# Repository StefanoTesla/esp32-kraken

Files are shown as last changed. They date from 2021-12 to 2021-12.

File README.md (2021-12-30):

# esp32 Kraken
A funny name for a simple pcb for a esp32 prototipe, designed to use all i/o as input and output with different configurations

This board is deisgned to imporve the quality of development forgetting the protobard with folating wires and no-contact noise.

The pcb is designed by eagle

The size of the board is 100x100mm perfect to pass as prototype in jlcpb and get it at a low price (around 22$ for 5 boards).

Currently the pcb is designed to fit with esp32 dev kit with 30pins

The pcb.zip file contain the geber file to upload in your favourite pcb manufacturing site ♥️

<p align="center">
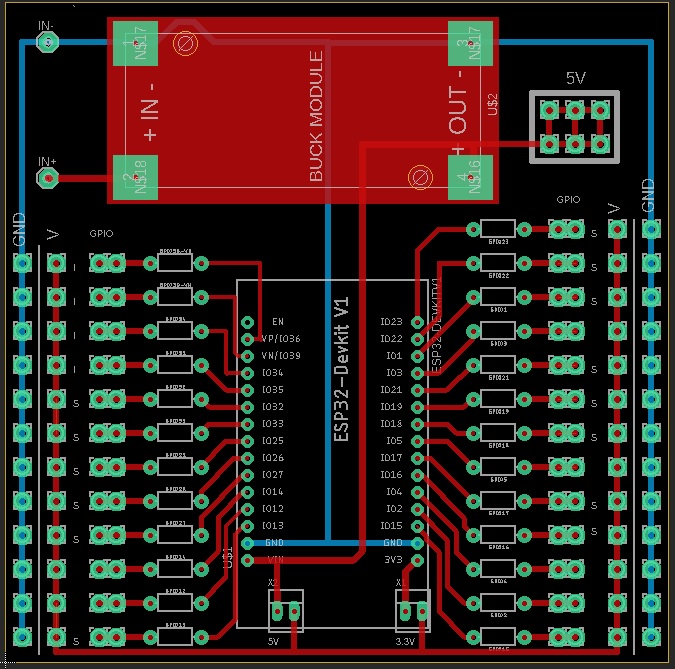
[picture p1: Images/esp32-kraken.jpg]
  
</p>

## How does it work?

Very well! 🙂 with this configuration you don't have limit, all I/O are ready to use in all the way you can think let's take a look:

### Power supply

If you want you can add a LM2596 DC-DC step down, otherwise you can give 5V directly on OUT+ and OUT-

<p align="center">
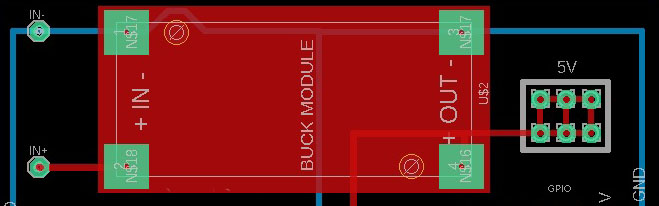
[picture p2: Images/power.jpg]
  
</p>

In the right side there's some 5V spare pins where you can pluc i2c devices or what you want

### V voltage selector
As you can see there's a GND and a V pin for each input, you can choose the V voltage as you prefer in 5V or 3.3V bridgin one of the the selector in the buttom, or give your own voltage to the V line (this will help cause 3.3V are providev from internal esp32 voltage regulator

<p align="center">
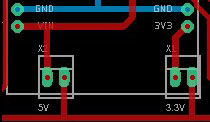
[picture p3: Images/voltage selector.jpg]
  
</p>

### Input

Free to choose in wich way you wanna use it, in the past I hade some problem using internal pull up/pull down resistor and this is why I build this board in a first step.

You can provide olso 5V signal to the esp32 adding a zener diode, or a fancy 10K resistor but after don't cry if your esp32 blow up 🤯 furthermore the ground of all two system shuold be connected between

#### External Pull Up/Down Resistor

Pull down:
<p align="center">
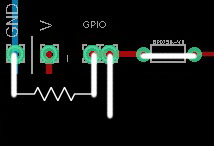
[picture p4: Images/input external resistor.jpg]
  
</p>

Pull Up
<p align="center">
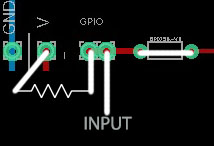
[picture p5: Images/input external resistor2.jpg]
  
</p>

#### Directly input

You can give olso direct input of coure in two way, the white one, is more boring, you need a bridge but can be useful if you neet to measure the volatage, for the listless there's olso the red one solution

<p align="center">
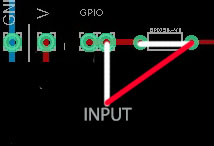
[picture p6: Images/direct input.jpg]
  
</p>

#### Others funny thing you can do

You can use a zener with resistor for limit the voltage, you can use a capacitor with a resistor for having an external debounce system, but be careful adding a lot of thing or your board become a christmas tree 🎄

### Output

Output can be use in three differt way, directly like the input with the same method, you can usa a bridge to measuere the voltage (yellow way) or plug the wire directly before gpio resistance (white way) , if you wanna plug a led you can simply add a resistor in the appropriate space (red way)

<p align="center">
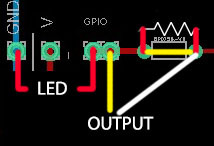
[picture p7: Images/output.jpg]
  
</p>

### Board notes

If you are not myopic you can see an I or an S near some GPIO, what they mean???

I stand for Only-Input GPIO

S stand for "Safety" that is you can use that output without going to have problems like pwm at the boot

<p align="center">
  
</p>

## Hope you like it!

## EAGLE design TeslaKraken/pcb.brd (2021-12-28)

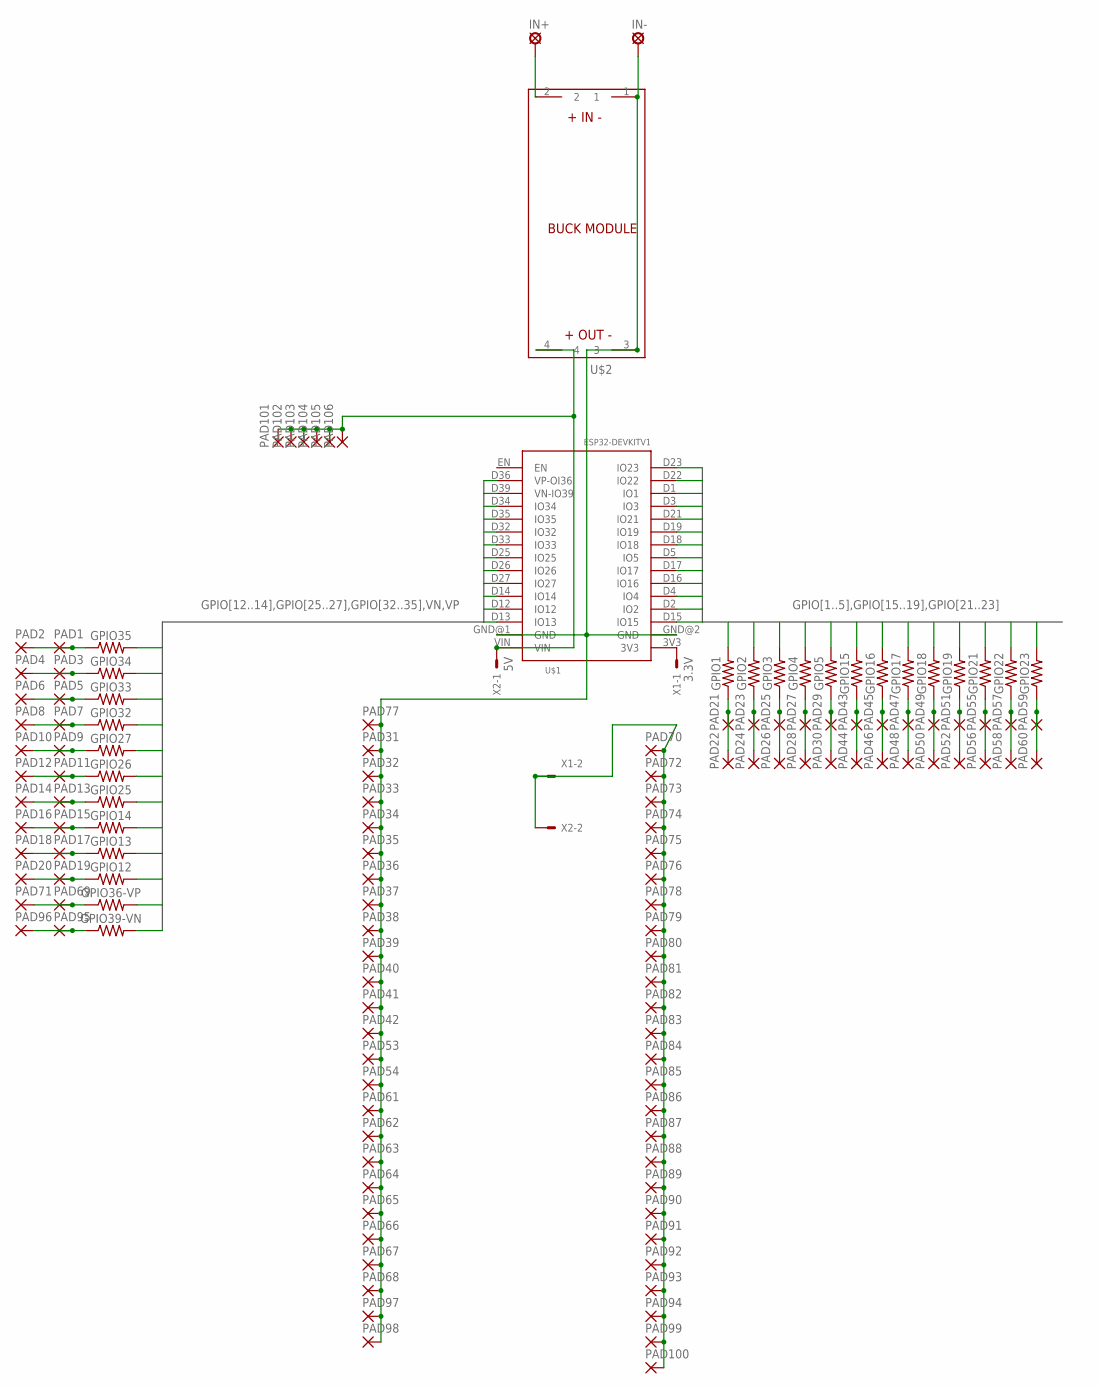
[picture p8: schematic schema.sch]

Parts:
GPIO1, GPIO2, GPIO3, GPIO4, GPIO5, GPIO12, GPIO13, GPIO14, GPIO15, GPIO16, GPIO17, GPIO18, GPIO19, GPIO21, GPIO22, GPIO23, GPIO25, GPIO26, GPIO27, GPIO32, GPIO33, GPIO34, GPIO35, GPIO36-VP, GPIO39-VN: AXIAL-0.3-KIT
IN+: SE14
IN-: SE14
PAD1, PAD2, PAD3, PAD4, PAD5, PAD6, PAD7, PAD8, PAD9, PAD10, PAD11, PAD12, PAD13, PAD14, PAD15, PAD16, PAD17, PAD18, PAD19, PAD20, PAD21, PAD22, PAD23, PAD24, PAD25, PAD26, PAD27, PAD28, PAD29, PAD30, PAD31, PAD32, PAD33, PAD34, PAD35, PAD36, PAD37, PAD38, PAD39, PAD40, PAD41, PAD42, PAD43, PAD44, PAD45, PAD46, PAD47, PAD48, PAD49, PAD50, PAD51, PAD52, PAD53, PAD54, PAD55, PAD56, PAD57, PAD58, PAD59, PAD60, PAD61, PAD62, PAD63, PAD64, PAD65, PAD66, PAD67, PAD68, PAD69, PAD70, PAD71, PAD72, PAD73, PAD74, PAD75, PAD76, PAD77, PAD78, PAD79, PAD80, PAD81, PAD82, PAD83, PAD84, PAD85, PAD86, PAD87, PAD88, PAD89, PAD90, PAD91, PAD92, PAD93, PAD94, PAD95, PAD96, PAD97, PAD98, PAD99, PAD100, PAD101, PAD102, PAD103, PAD104, PAD105, PAD106: 2,54/1,1
U$1: ESP32DEVKITV1; ESP32-DEVKITV1
U$2: BUCK_MODULEWITH_SMDPADS&THROUGHHOLES; BUCK_MODULE
X1: 3.3V; 22-23-2021
X2: 5V; 22-23-2021

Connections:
GPIO1: GPIO1.P$2 (2), U$1.D1 (IO1)
GPIO2: GPIO2.P$2 (2), U$1.D2 (IO2)
GPIO3: GPIO3.P$2 (2), U$1.D3 (IO3)
GPIO4: GPIO4.P$2 (2), U$1.D4 (IO4)
GPIO5: GPIO5.P$2 (2), U$1.D5 (IO5)
GPIO12: GPIO12.P$2 (2), U$1.D12 (IO12)
GPIO13: GPIO13.P$2 (2), U$1.D13 (IO13)
GPIO14: GPIO14.P$2 (2), U$1.D14 (IO14)
GPIO15: GPIO15.P$2 (2), U$1.D15 (IO15)
GPIO16: GPIO16.P$2 (2), U$1.D16 (IO16)
GPIO17: GPIO17.P$2 (2), U$1.D17 (IO17)
GPIO18: GPIO18.P$2 (2), U$1.D18 (IO18)
GPIO19: GPIO19.P$2 (2), U$1.D19 (IO19)
GPIO21: GPIO21.P$2 (2), U$1.D21 (IO21)
GPIO22: GPIO22.P$2 (2), U$1.D22 (IO22)
GPIO23: GPIO23.P$2 (2), U$1.D23 (IO23)
GPIO25: GPIO25.P$2 (2), U$1.D25 (IO25)
GPIO26: GPIO26.P$2 (2), U$1.D26 (IO26)
GPIO27: GPIO27.P$2 (2), U$1.D27 (IO27)
GPIO32: GPIO32.P$2 (2), U$1.D32 (IO32)
GPIO33: GPIO33.P$2 (2), U$1.D33 (IO33)
GPIO34: GPIO34.P$2 (2), U$1.D34 (IO34)
GPIO35: GPIO35.P$2 (2), U$1.D35 (IO35)
unnamed: GPIO35.P$1 (1), PAD1.1, PAD2.1
unnamed: GPIO34.P$1 (1), PAD3.1, PAD4.1
unnamed: GPIO33.P$1 (1), PAD5.1, PAD6.1
unnamed: GPIO32.P$1 (1), PAD7.1, PAD8.1
unnamed: GPIO27.P$1 (1), PAD9.1, PAD10.1
unnamed: GPIO26.P$1 (1), PAD11.1, PAD12.1
unnamed: GPIO25.P$1 (1), PAD13.1, PAD14.1
unnamed: GPIO14.P$1 (1), PAD15.1, PAD16.1
unnamed: GPIO13.P$1 (1), PAD17.1, PAD18.1
unnamed: GPIO12.P$1 (1), PAD19.1, PAD20.1
unnamed: GPIO1.P$1 (1), PAD21.1, PAD22.1
unnamed: GPIO2.P$1 (1), PAD23.1, PAD24.1
unnamed: GPIO3.P$1 (1), PAD25.1, PAD26.1
unnamed: GPIO4.P$1 (1), PAD27.1, PAD28.1
unnamed: GPIO5.P$1 (1), PAD29.1, PAD30.1
unnamed: PAD101.1, PAD102.1, PAD103.1, PAD104.1, PAD105.1, PAD106.1, U$1.VIN, U$2.4, X2.1
unnamed: IN-.MP, PAD31.1, PAD32.1, PAD33.1, PAD34.1, PAD35.1, PAD36.1, PAD37.1, PAD38.1, PAD39.1, PAD40.1, PAD41.1, PAD42.1, PAD53.1, PAD54.1, PAD61.1, PAD62.1, PAD63.1, PAD64.1, PAD65.1, PAD66.1, PAD67.1, PAD68.1, PAD77.1, PAD97.1, PAD98.1, U$1.GND@1 (GND), U$1.GND@2 (GND), U$2.1, U$2.3
unnamed: IN+.MP, U$2.2
unnamed: GPIO36-VP.P$1 (1), PAD69.1, PAD71.1
unnamed: PAD70.1, PAD72.1, PAD73.1, PAD74.1, PAD75.1, PAD76.1, PAD78.1, PAD79.1, PAD80.1, PAD81.1, PAD82.1, PAD83.1, PAD84.1, PAD85.1, PAD86.1, PAD87.1, PAD88.1, PAD89.1, PAD90.1, PAD91.1, PAD92.1, PAD93.1, PAD94.1, PAD99.1, PAD100.1, X1.2, X2.2
unnamed: GPIO39-VN.P$1 (1), PAD95.1, PAD96.1
unnamed: GPIO15.P$1 (1), PAD43.1, PAD44.1
unnamed: GPIO16.P$1 (1), PAD45.1, PAD46.1
unnamed: GPIO17.P$1 (1), PAD47.1, PAD48.1
unnamed: GPIO18.P$1 (1), PAD49.1, PAD50.1
unnamed: GPIO19.P$1 (1), PAD51.1, PAD52.1
unnamed: U$1.3V3, X1.1
unnamed: GPIO21.P$1 (1), PAD55.1, PAD56.1
unnamed: GPIO22.P$1 (1), PAD57.1, PAD58.1
unnamed: GPIO23.P$1 (1), PAD59.1, PAD60.1
VN: GPIO39-VN.P$2 (2), U$1.D39 (VN-IO39)
VP: GPIO36-VP.P$2 (2), U$1.D36 (VP-OI36)

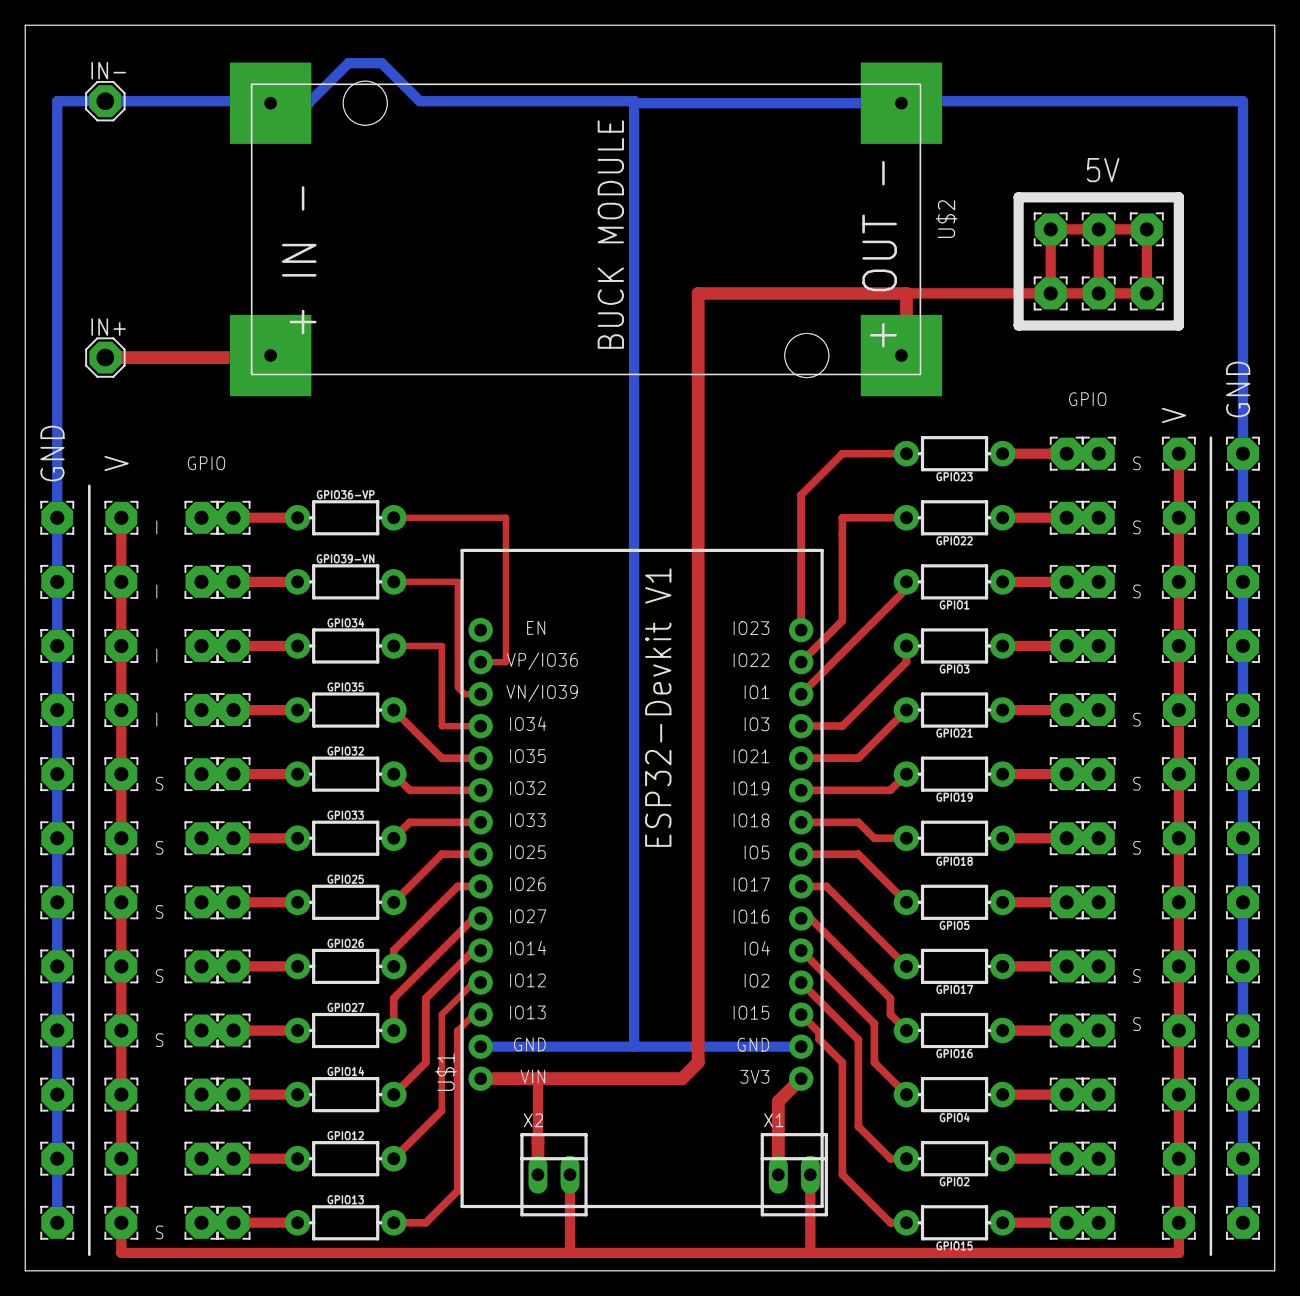
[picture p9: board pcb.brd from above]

Board: 2 copper layers, 99.0 x 98.7 mm, 137 parts (0 on the bottom side), 55 nets.

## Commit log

2021-12-28 Eagle Project
    [pcb.brd, schema.sch]
2021-12-30 Create voltage selector.jpg

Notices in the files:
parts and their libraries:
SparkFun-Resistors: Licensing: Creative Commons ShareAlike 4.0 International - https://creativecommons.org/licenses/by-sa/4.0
